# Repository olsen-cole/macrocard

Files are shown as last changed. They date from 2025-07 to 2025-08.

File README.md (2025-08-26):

# bannerWhiteTransparent

The ZMK config files for this project can be found [here](https://github.com/olsen-cole/zmk-config-macrocard).

The Macrocard is a wireless business card-shaped macropad featuring three switches, a rotary encoder, and RGB LED feedback. This macropad is designed for productivity workflows, media control, and presentation control.

> [!NOTE] 
> If you have received a Macrocard, the firmware will most likely be for Windows. To switch to Macintosh, see the firmware section.

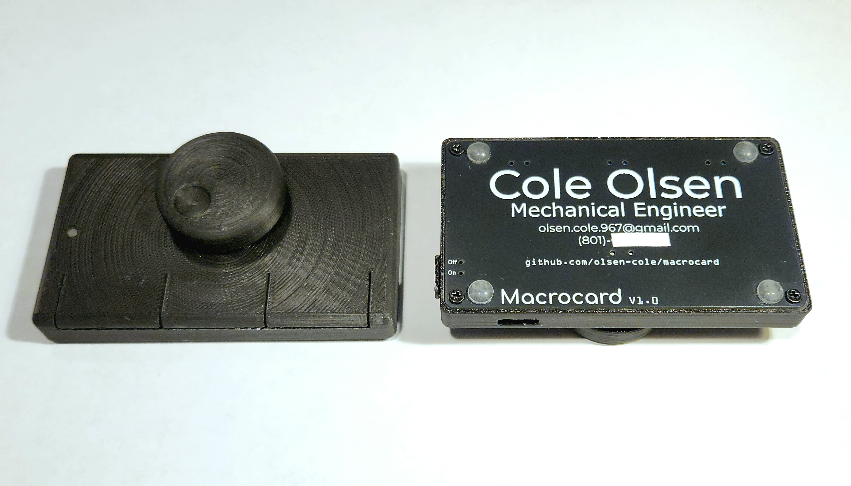
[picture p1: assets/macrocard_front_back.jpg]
Front/Back

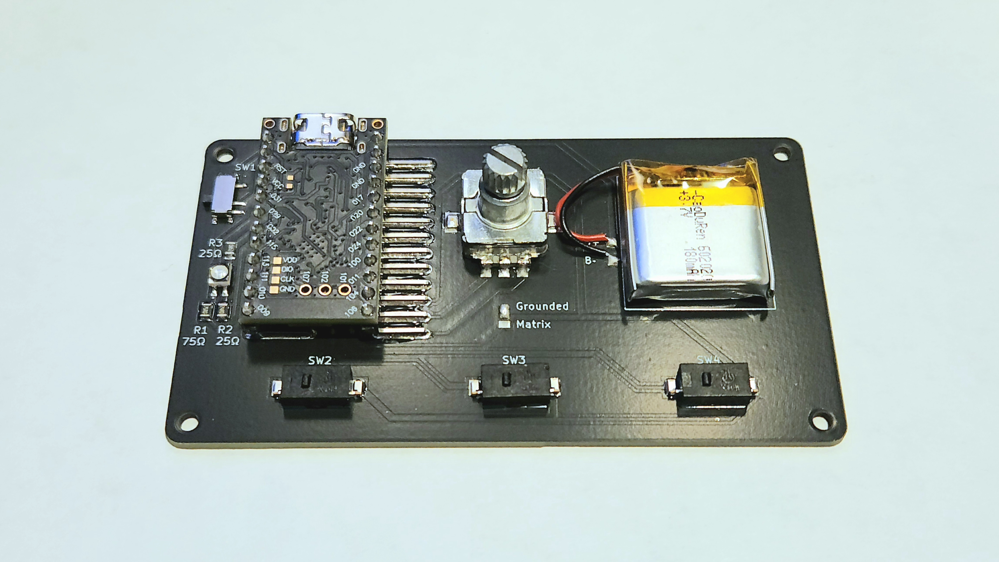
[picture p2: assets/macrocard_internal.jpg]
Internal


# Keymap
This macropad has three main layers: productivity, music, and presentation.

## Productivity
Pressing keys one and two will place the macropad into productivity mode. This layer is composed of three sub-layers: window switcher, virtual desktop switcher, and tab switcher.

### Window Switcher (Cyan)
Window switcher is the sub layer that is activated by default when entering the productivity layer. This layer can be activated by pressing the first key while in the productivity layer.

**Function:** Rotating the knob will switch between active windows. Press the knob to select a window.

### Virtual Desktop Switcher (Yellow)
This layer can be activated by pressing the second key while in the productivity layer.

**Function:** Rotating the knob will switch between virtual desktops.

### Tab Switcher (Magenta)
This sub-layer can be activated by pressing the third key while in the productivity layer.

**Function:** Rotating the knob will switch between active tabs on supported applications. Press the knob to select a tab.

## Music (Green)
Pressing keys two and three will place the macropad into music mode.

**Function:** Rotating the knob will adjust volume. Pressing the knob will mute/unmute audio. The three keys control previous track, play/pause, and forward track.

## Presentation (Red)
Pressing keys one and three will place the macropad into presentation remote mode.

**Function:** Rotating the knob will navigate slides. Pressing the knob wil activate presenter view. The three keys will start presentation, exit presentation, and toggle blank screen.

> [!NOTE] 
> On any layer, pressing and holding the encoder switch will disconnect from the current connected device.

# Usage
After three hours of inactivity, the macropad will enter an idle state to save energy. After six hours of inactivity, the macropad will enter a deep sleep mode. With these modes, the macropad can last a little under a month on a single charge. If you need to store the macropad, turn the macropad off using the on/off switch to disconnect the battery.

> [!NOTE] 
> Since the on/off switch will disconnect the battery, charging the battery is not possible when the macropad is off.

# Firmware
There are three firmware files—one for Windows, one for Macintosh, and one to reset. In order to update, re-flash, or change firmware, connect the macropad to a computer through USB and press all three keys and the encoder switch to enter bootloader mode. The macropad should now show as a drive. Simply copy and paste the uf2 file to apply the update.

> [!NOTE] 
> If the macropad will not enter bootloader mode through the shortcut, the bootloader mode can be manually activated by shorting the RST pin to the ground pin above it.

# Known Issues
- The macropad may fail to wake from deep sleep. Simply connect the macropad through USB and it should wake.
- The macropad will occasionally display a pink color on wake when it should be cyan. Switching the layer resolves the issue.

# Troubleshooting
If you cannot connect to the macropad despite the device broadcasting, the unit may have a previous saved connection. Press and hold the encoder switch to clear the saved bluetooth connection and retry connecting.

If any issues are encountered during or after the update process, performing a settings reset may resolve issues. To do this, first disassemble the macropad. Place the macropad into bootloader mode manually and apply the settings_reset.uf2 file. Then place the macropad into bootloader mode manually and apply the update file.

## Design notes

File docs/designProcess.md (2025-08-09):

# Design Process
Inspired by the numerous over-engineered business cards that I've seen on [Hackaday](https://hackaday.com/tag/business-card), I wanted to design a card useful enough to stick around the office. Combining my love of DIY input devices with a bit of CAD experience, I decided to design a business card-shaped macropad.

## Initial Design Choices
Design choices were made primarily due to cost, ease of manufacturing, and simplicity.

- The nice!nano microcontroller was selected over an integrated SoC or a microcontroller with castellated pads due to cost and ease of assembly.

- A low profile ec11 encoder was selected over a slimmer mouse wheel encoder due to the direct support within ZMK.

## Board Design

I first designed a PCB with flux.ai. The circuit required for this project was simple enough to require only two layers due to the small amount of I/O. 

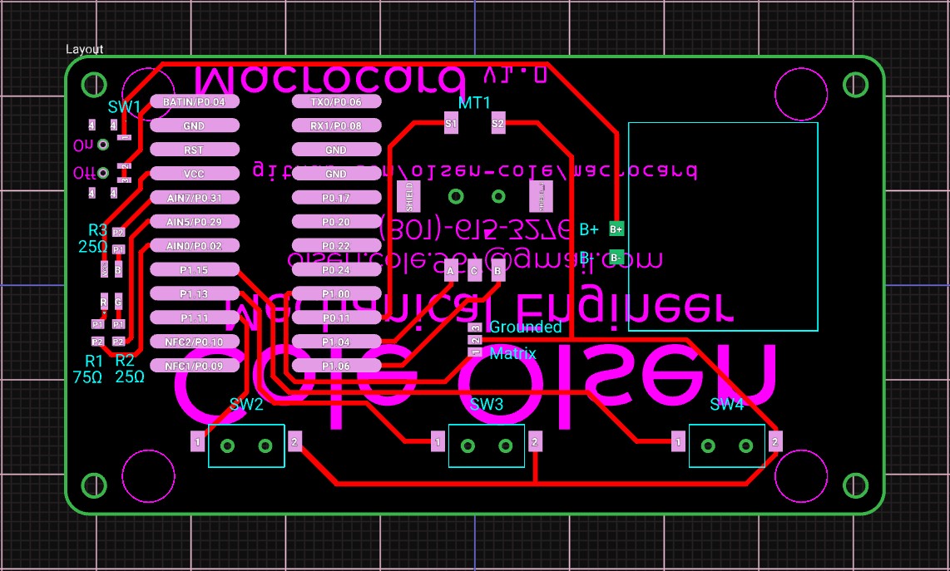
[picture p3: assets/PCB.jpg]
PCB


Although it is possible to surface mount a board with female through-hole connections, I opted for right angle headers to surface mount the nice!nano.

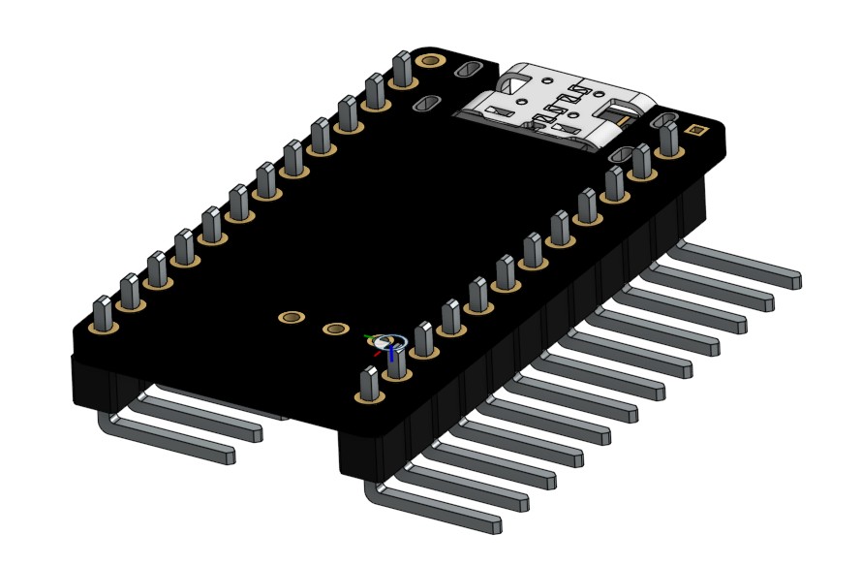
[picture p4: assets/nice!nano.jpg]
nice!nano


The other notable components used for this project were a simple four leg RGB LED, mouse microswitches, a 10mm plum shaft encoder, and a 602020 LiPo battery. Finally, a low profile switch was added to disconnect the battery during storage.

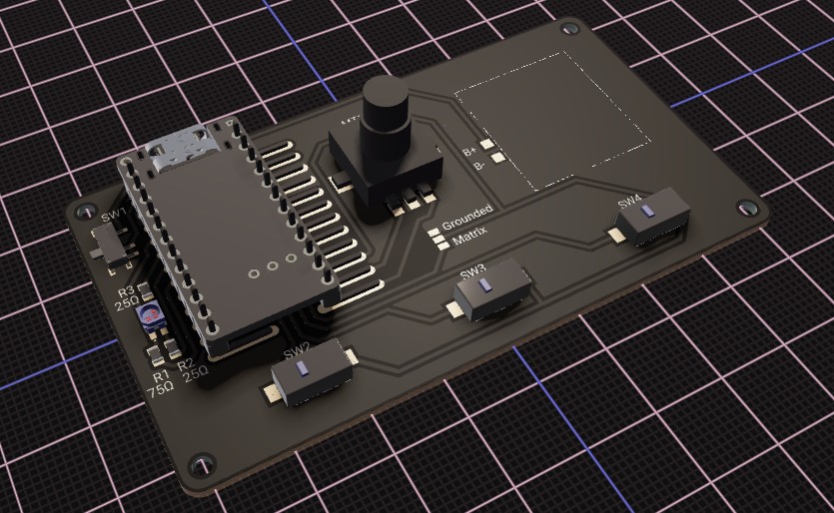
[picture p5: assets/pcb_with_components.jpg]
PCB with components


## Firmware Design

Before ordering PCBs, I started working on the firmware to confirm that the circuit would work. The two big keyboard firmware projects with support for the NRF52840 are ZMK and BlueMicro. Initially, I began development with BlueMicro as it could remember the last active layer on powerup. However, I required ZMK for a more complex layer system.

ZMK development took some time. I first started working on the layers, of which I was able to create three "modes" out of layers which could be accessed by pressing a combination of two out of the three keys. 

Once the layers were functional, I began implementing the [zmk-smart-toggle behavior](https://github.com/caksoylar/zmk-smart-toggle?tab=readme-ov-file) to enable the window/tab switcher. This allowed for a sleek implementation of the alt-tab shortcut on a rotary encoder. Finally, I implemented the [zmk-rgbled-widget](https://github.com/olsen-cole/zmk-rgbled-widget) to give feedback on the active layer, bluetooth connectivity, and battery status.  

After compiling a working firmware, I began implementing a forked version of the RGB LED widget as I was not satisfied with the lack of PWM brightness control. I accomplished this by implementing the PWM functionality provided by zephyr, the project that zmk is built on.

## Shell Design

Once the firmware was completed, I ordered the PCBs and began working on a shell. I decided to implement bending tops for the keyswitches. After some testing, I found a thickness of 0.4mm allowed for a somewhat durable hinge without adding too much resistance to the keypress.

My first prototypes of the shell included a two part extension of the switch. After testing, I found that I could print the extension in place.

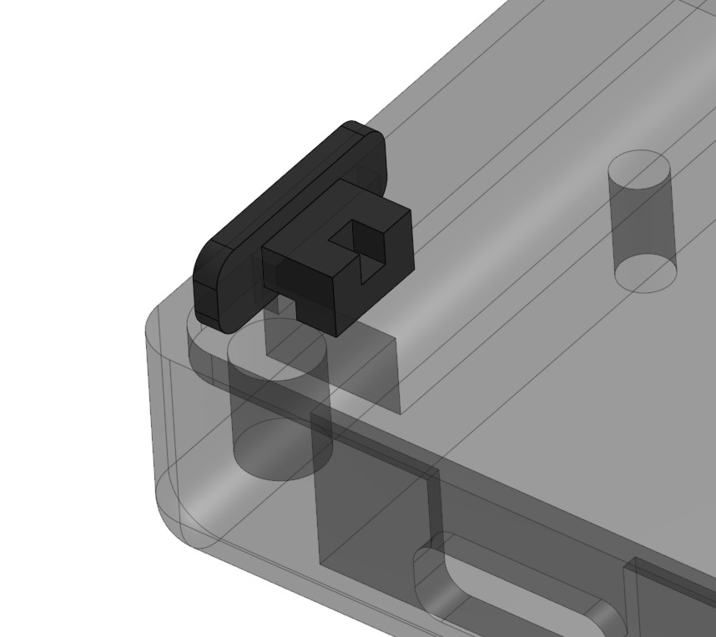
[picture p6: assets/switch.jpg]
switch


The final component of the shell is the encoder knob. I wanted a large knob that hovered over the top of the macropad. However, as the shell would need to lift up from the macropad to disassemble, I needed a way to remove the knob. I decided to cut the knob into a top and a base, joined with a magnet. To prevent tolerance issues, I added a taper in the connection.

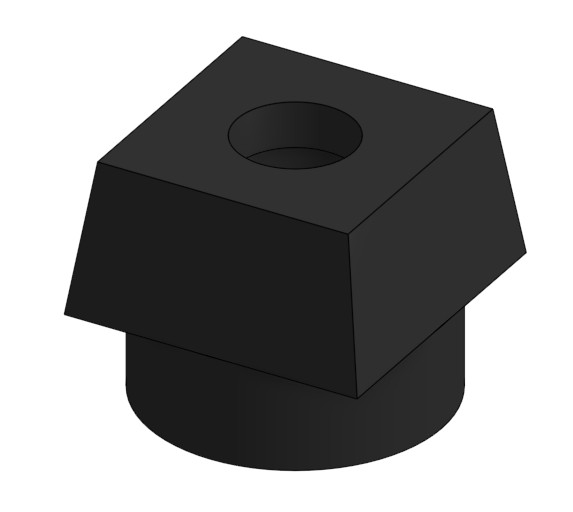
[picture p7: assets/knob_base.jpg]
knob base


## Future Work

My first regret with this project is the shell. Most over-engineered business card projects are simply the PCB itself, no shell. However, I did need some way to display skills more relevant to mechanical engineering. It did also give me experience designing flexible and print-in-place components.

My second regret was using flux.ai. Although it is perfect for quickly designing boards, it lacked many advanced features. It also lacked a schematic export. In the future, I'll stick to KiCad.

For version two of this project, I will select components to keep the lowest profile possible.

* Onboard Controller
    * NRF52840 QFAA
    * Charging and regulator circuits similar to nice!nano
* LIR2032 LiPo battery
    * Build battery protection into board
    * SMD Coin cell clip, <8mm height
* Horizontal mouse scroll wheel as rotary encoder
    * Low profile (<2.8mm)
    * Custom ZMK configuration as the EC11 is the only supported encoder
* Kailh PG1316 Switches
    * Low profile (<5mm with keycap)

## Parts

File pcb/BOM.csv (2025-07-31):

Component Description | QTY | Ref Des | P/N #
PLCC4 RGB LED 3528 Common Anode | 1 | D1
EC11 10mm plum shaft | 1 | MT1 | RIC11-31S10K2-GSMT
Resistor, 75Ω, SMD_0805_2012Metric | 1 | R1
Resistor, 25Ω, SMD_0805_2012Metric | 2 | R2,R3
Slide Switches, SW-TH_MSK12C02 | 1 | SW1 | MSK12CO2-SZ
Surface Mount Mini Switch | 3 | SW2,SW3,SW4 | D2LS-11
nice!nano V2 Microcontroller | 1 | U1 | nice_nano
602020 LiPo Battery | 1 | BT1
Right Angle Positive 12 pos 2.54mm Pitch Header | 2
M2 Heat Insert | 4
M2 5mm Screw | 4
2mm Light Pipe | 1
5mmx2mm Magnet | 2
6mmx2mm Rubber Bumper | 4

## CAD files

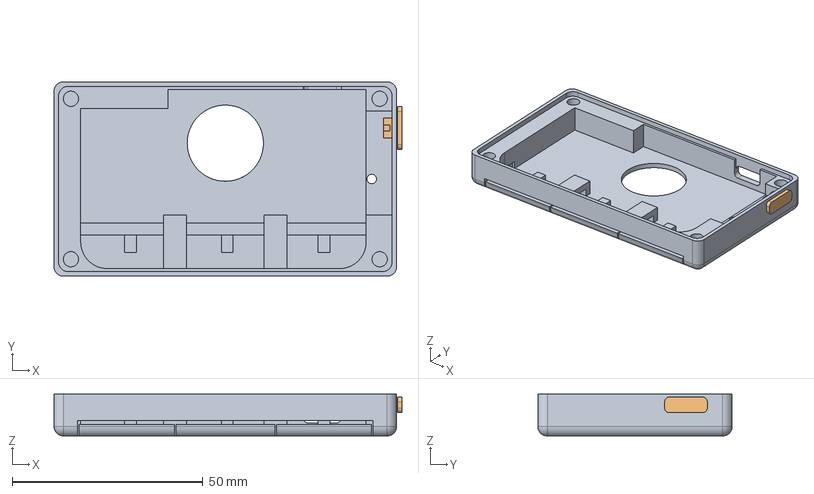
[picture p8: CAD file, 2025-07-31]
case/Bottom + Switch.step
91.3 x 51.0 x 11.0 mm
Switch

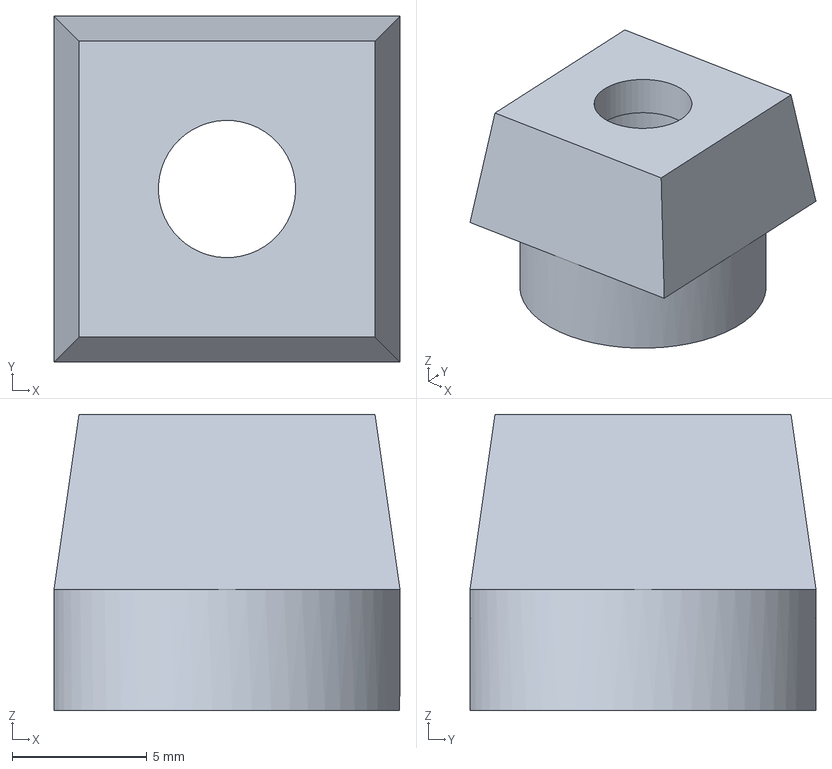
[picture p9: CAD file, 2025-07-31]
case/Knob base.step
12.9 x 12.9 x 11.0 mm

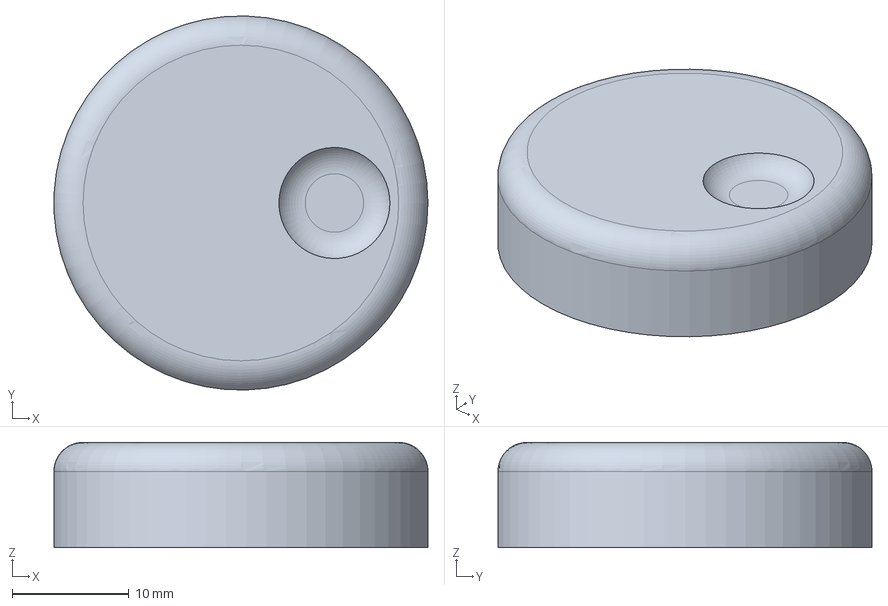
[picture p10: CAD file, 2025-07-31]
case/Knob top.step
32.0 x 32.0 x 9.00 mm

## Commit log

2025-07-31 Add files
    Add case files, BOM, and update readme
    [BOM.csv, Bottom + Switch.step, Knob base.step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]
2025-08-09 Update docs
    Added a picture of the PCB with components
